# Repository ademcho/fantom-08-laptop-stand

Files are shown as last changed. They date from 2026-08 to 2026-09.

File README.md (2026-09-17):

# Fantom-08 laptop stand

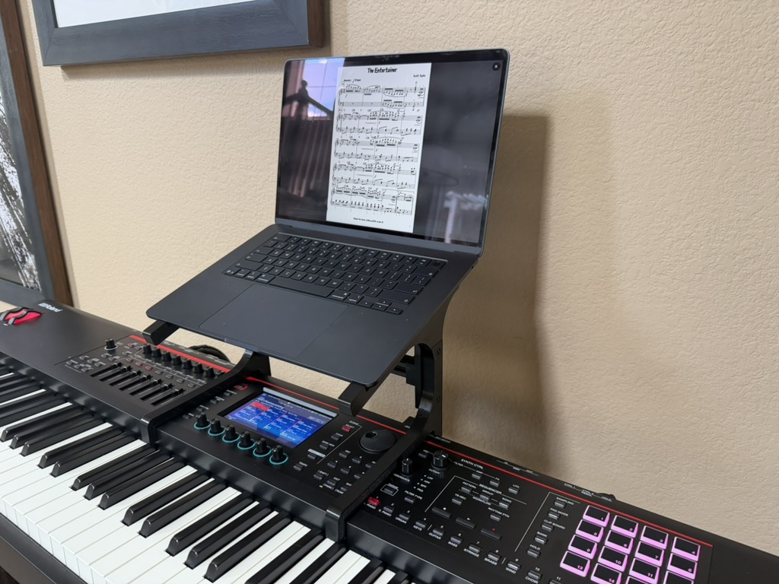
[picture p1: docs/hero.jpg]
Laptop on the stand above a Fantom-08


Clip-on laptop stand for a Roland Fantom-08. Print two brackets; they hook over the rear
panel and under the case bottom at the two clear spots on the panel. Laptop sits on the
15° tray. An optional cross brace (a 2020 aluminum extrusion between the brackets) stiffens
the pair side-to-side.

Design lives in Onshape: `Part Studio 1` is the source profile (one sketch + 15 mm extrude).
`Fantom Stand - Bracket 1.2 split` and `Fantom Stand - Brace mount` are generated.

| | |
|---|---|
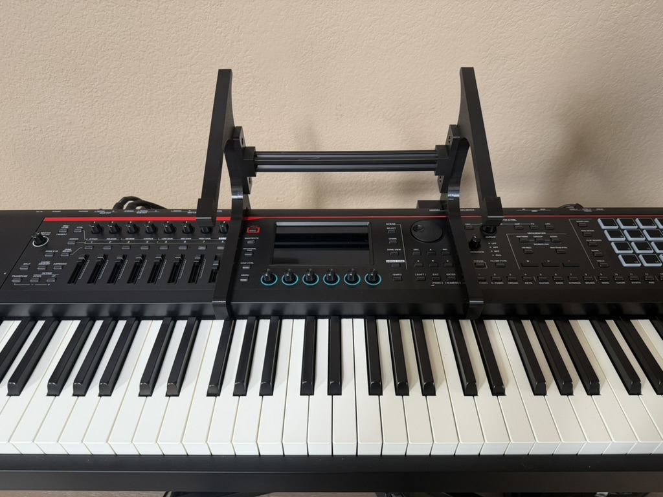
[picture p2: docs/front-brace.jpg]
Both brackets with the 2020 extrusion brace
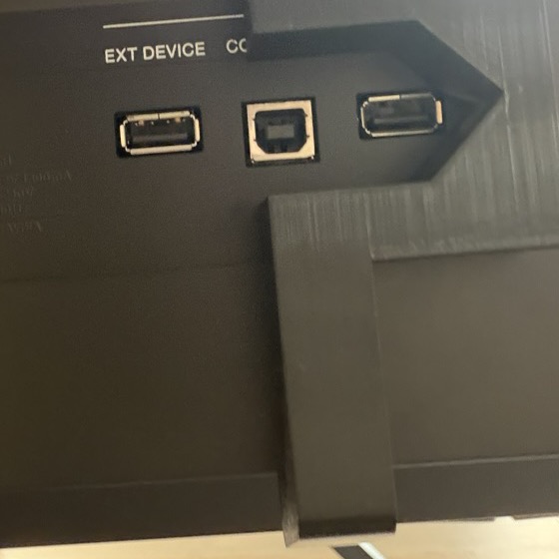
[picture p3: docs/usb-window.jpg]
The USB window clearing the rear ports
|  |  |

## Print

The bracket is 286 mm tall — too big for a 256 mm bed — so it's split on the post with an
86 mm half-lap joint. Print one **A** set and one **B** set (B is mirrored so that, with the
brackets facing each other, both keep their nut pockets on the outer face and a flat inner
face for the brace plate). A halves only mate with A, B with B — the lap is handed.

| file | size (mm) | qty | lay on bed |
|---|---|---|---|
| `exports/bracket_bottom_A.stl` / `_B` | 200 × 221 × 15 | 1 each | nut-pocket face down |
| `exports/bracket_top_A.stl` / `_B` | 213 × 144 × 15 | 1 each | plain face down (tongue step up) |
| `exports/bracket_bottom_B_usb.stl` | 200 × 221 × 46 | instead of `_B` on a Fantom-08 | nut-pocket face down |
| `exports/brace_mount.stl` | 28 × 90 × 20 | 2 | flat back down |

The player's-right bracket lands on the rear USB cluster, so its bottom half is `_B_usb`: the post
is cut away over the port band (28 mm wide, 6 mm vertical margin on your 54 / 28 mm measurements)
and rerouted as a hump on the inner face with a 45° gable roof, so it still prints flat with no
supports. Constants are at the bottom of `tools/split.py` if the ports sit elsewhere.

Flat, no supports. PETG, 4+ walls, 30 %+ infill. Layers run along the post and tray, which
is the strong direction; never print these standing up.

### Replacement bottoms: more key clearance (2026-09-16)

The downward key-facing hook is now **2.5 mm shorter** (17.5 mm below the arm,
previously 20 mm). The 170 mm opening, top halves, lap joints, brace attachment and
USB window remain unchanged. Existing owners only need to reprint the two bottoms.

Open [bottom_brackets_key_clearance_X2D.3mf](exports/bottom_brackets_key_clearance_X2D.3mf)
in Bambu Studio and print **both plates**: plate 1 is right B with USB clearance;
plate 2 is left A. They are already flat, nut-pocket face down. PETG, 0.4 mm nozzle,
0.20 mm layers, 4 walls, 30% infill, **no supports**. Estimated total: **137 g / 3 h 53 min**.
Select your actual bed and PETG, then re-slice; the project contains no cached G-code.
Check clearance with the nearby keys released and pressed after installation.

The source Onshape export is retained; `HOOK_SHORTEN` in `tools/split.py` applies
this trim on regeneration. CAD comparison confirmed only the hook tips changed,
upper STLs are byte-identical, and both bottoms sliced without mesh repairs or
skipped/out-of-bed objects. [Verification record](exports/bottom_reprint_check.json).

### Fully printable brace (alternative to the extrusion)

No aluminum, no extra fasteners: a telescoping square tube that plugs into the same brace
plate sockets and is captive once the brackets are mounted. Measure plate face to plate
face, set `SPAN` in `tools/brace_beam.py`, run it, print what it lists (1, 2, or 3 pieces
depending on span; up to ~625 mm). Tube bores have a 45° roof — insert rods roof-up.
Lighter duty than the extrusion; use the extrusion if the frame ever feels rubbery.

### Fit coupons

`tools/coupons.py` generates thin (5 mm) slices of the clamp profile with the opening
(rear wall → keybed lip) enlarged by +1.0/+1.5/+2.0/+2.5 mm —
`exports/coupon_plus*.stl`, size engraved on each. Print flat, 2 walls / ~10 % infill.
The stretch is mid-arm only; post, foot, and joint are untouched, so the winning delta
can be applied to the arm length in the source sketch without breaking the lap joint.
The +1.0 coupon won (2026-09-06): the sketch now has the opening at 170 mm, and the arm
over the rear panel was dropped from 20 to 12 mm tall at the same time — it only bears on
the panel and pulls on the lip, and the lower bar is ~5× easier to spring on and blocks
less of the panel. Coupons are still cut from the current profile if you need to re-run.

## Hardware

- 4 × M4 pan head, **×20 without brace / ×25–30 with brace** (2 per bracket; they are the
  lap-joint bolts, and with the brace the same bolts also hold the brace plates)
- 4 × M4 hex nut — drops into the hex pocket on the bracket's outer face
- 1 × 2020 aluminum extrusion (European standard, 6 mm slot), cut to plate face to plate
  face + 2 × 10 mm sockets, a couple of mm short: **260 mm** for the measured 11⅛" (282.6 mm)
  bracket spacing (plate faces 242.6 apart)
- optional: 2 × M5 × 16 pan head, self-tapped into the extrusion's ~4.2 mm center bore
  through the back of each brace plate (the extrusion is already captive once both brackets
  are mounted; the screws only matter if you want the frame rigid off the keyboard)

Example Amazon (US) sources, checked 2026-08-30: M4 assortment kit with nuts+washers
[B08FQRWWCM](https://www.amazon.com/dp/B08FQRWWCM) ~$9 · 2020 extrusion 2×1000 mm
[B08934HPRR](https://www.amazon.com/dp/B08934HPRR) ~$30 (or ZYLtech
[B07Z787MB8](https://www.amazon.com/dp/B07Z787MB8)) · M5×16
[B009TE2OMU](https://www.amazon.com/dp/B009TE2OMU). Any European-standard 2020 with a
6 mm slot works; if the M5 spins in the bore, tap it M5 or use thread-locker.

## Assembly

1. Slide each bracket's tongues together (A with A, B with B).
2. Braceless: M4×20 from the plain face, nut in the hex pocket, tighten. Done.
3. With brace: screw the extrusion into the two brace plates first (optional M5s through
   the plate backs), then bolt each plate over a bracket's inner face — M4×25 through
   plate + bracket, head sunk in the plate's counterbore, nut in the bracket's hex pocket.

## Regenerate after editing the profile

```
.venv/bin/python tools/fetch_step.py   # pulls exports/bracket_current.step from Onshape
.venv/bin/python tools/split.py
.venv/bin/python tools/brace.py
```

`tools/onshape.py` is a tiny authenticated GET/POST wrapper (creds in
`~/.config/onshape/credentials.env`). Joint and brace parameters (lap span, bolt positions,
clearances, socket size) sit at the top of `split.py` / `brace.py`; bolt positions must match
between the two.

## License

Models, exports, and code: [CC BY 4.0](LICENSE). Print it, remix it, sell it; just credit
Abe Demcho and link back here.

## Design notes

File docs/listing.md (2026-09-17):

# Listing copy for Printables / MakerWorld / Thingiverse

Paste-ready. Same text on all three; only the upload set differs (below).

## Title

Fantom-08 clip-on laptop stand (no drilling, removable, with cross brace)

## Summary (one line)

Two printed brackets hook the Roland Fantom-08 rear panel and hold a laptop on a 15° tray above the keys. No screws into the keyboard, on and off in seconds.

## Description

I wanted my laptop above my Fantom-08 without a separate stand taking floor space. These two brackets hook over the rear panel and under the case at the two clear spots on the back, and hold a 15° tray about 10 cm above the top panel. Nothing touches the keys or the screen, and it lifts straight off.

**What you get**

- Two brackets, each printed in two halves (they're 280 mm tall, too big for a 256 mm bed) joined by an 86 mm half-lap with two M4 bolts. The joint is stiffer than the print itself.
- The right-hand bracket has a window that clears the rear USB cluster; the post reroutes around it on the inside with a 45° gable so it still prints flat, no supports.
- Optional cross brace between the brackets: either a 2020 aluminum extrusion in printed socket plates, or a fully printed telescoping square tube. Braceless is fine for a 14"; use the brace for a 16" or if you move the keyboard around.
- Fit coupons: 5 mm slices of the clamp profile in +1.0 / +1.5 / +2.0 / +2.5 mm so you can check the opening on your unit before printing 200 g of PETG. My Fantom-08 wanted +1.0, and that's already in the main files.

**Key-clearance revision (2026-09-16):** the downward hook is 2.5 mm shorter.
Existing owners can reuse the upper halves and reprint only bottom A and bottom B USB.
The GitHub repo includes an X2D project containing just these two replacements.

**Print**

PETG, 0.2 mm layers, 4+ walls, 30 %+ infill. Every part lies flat, no supports. Print the halves with the layers running along the post and tray (the strong direction); never stand them up. Right-hand bottom half uses the `_usb` file. Hardware: 4 × M4×20 pan head (×25 with the brace plates), 4 × M4 nuts. Full instructions, cut lengths, and the source in the GitHub repo.

**Source**

Profile is an Onshape sketch; the splitting, joint, brace, and coupons are generated with build123d (Python). Repo: https://github.com/ademcho/fantom-08-laptop-stand · Onshape: https://cad.onshape.com/documents/9a86687b513359acbe40631b

Only tested on the Fantom-08. The 06 and 07 have the same case, so it should fit, but measure your rear panel: the opening is 170 mm rear wall to keybed lip and the panel is 96 mm tall.

## Files to upload

| file | qty | note |
|---|---|---|
| bracket_bottom_A.stl | 1 | left |
| bracket_bottom_B_usb.stl | 1 | right, with USB window |
| bracket_top_A.stl | 1 | |
| bracket_top_B.stl | 1 | |
| brace_mount.stl | 2 | only with the extrusion brace |
| brace_outer.stl, brace_inner.stl | 1 each | only with the printed brace |
| coupon_plus1.0mm.stl … plus2.5mm | optional | fit test |

Skip bracket_bottom_B.stl (plain right side) unless someone asks; it's in the repo.

## Print settings (the form fields)

Printer: any 256 mm bed · Material: PETG · Layer: 0.2 · Walls: 4 · Infill: 30 % gyroid · Supports: none · Rafts: none · Filament: ~280 g total for four halves.

## Tags

roland, fantom, fantom-08, fantom08, keyboard, synthesizer, laptop-stand, laptop, music, studio, stand, bracket, clip-on, petg

## Category

Printables: Hobby & Makers → Music · MakerWorld: Music · Thingiverse: Music

## Photos to take (the listing lives or dies on the first one)

1. Hero: the whole keyboard from the player's side, laptop open on the stand, screen on. Slightly above eye level, landscape.
2. Rear three-quarter: shows both brackets hooking the panel and the brace. This is the one people study.
3. Close-up of the USB window with a cable plugged in.
4. Close-up of the lap joint with the bolts, before the brace plate goes on.
5. All parts laid out on the bed or a table, so people see the print count.
6. Optional: the laptop lid closed, to show it doesn't block the screen or the keys.

Phone is fine. Daylight, no flash, wipe the dust off the Fantom first.

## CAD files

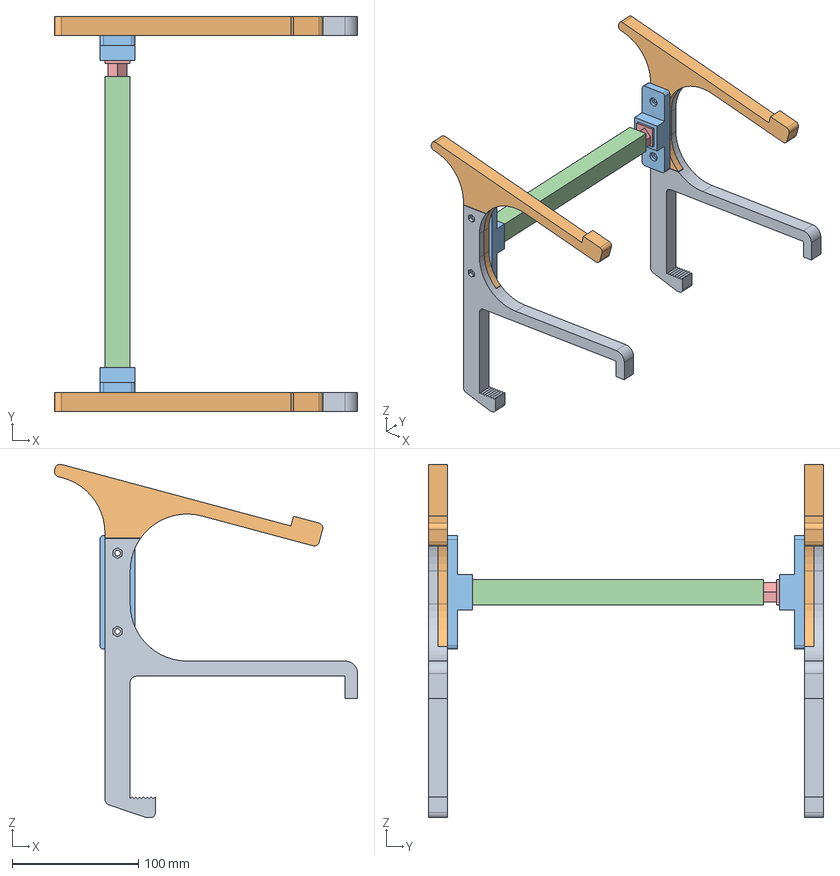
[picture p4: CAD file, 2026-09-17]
exports/full_assembly.step
240.0 x 312.6 x 279.7 mm
Bracket A bottom (clamp)
Bracket A top (tray)
Bracket B bottom (clamp)
Bracket B top (tray)
Brace plate A
Brace plate B
Brace outer tube
Brace inner rod

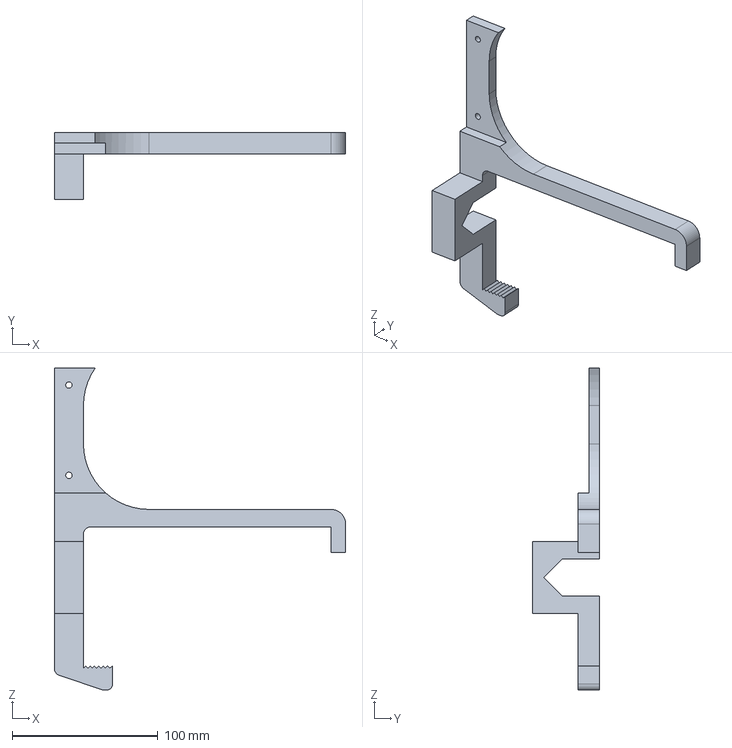
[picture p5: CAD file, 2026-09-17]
exports/bracket_bottom_B_usb.step
200.0 x 46.2 x 221.1 mm

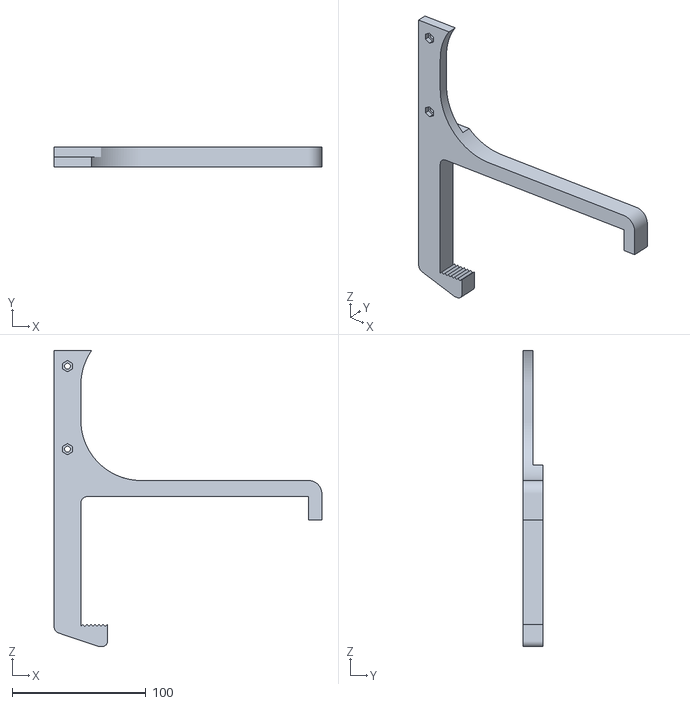
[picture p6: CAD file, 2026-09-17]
exports/bracket_bottom_A.stl
200.0 x 15.0 x 221.1

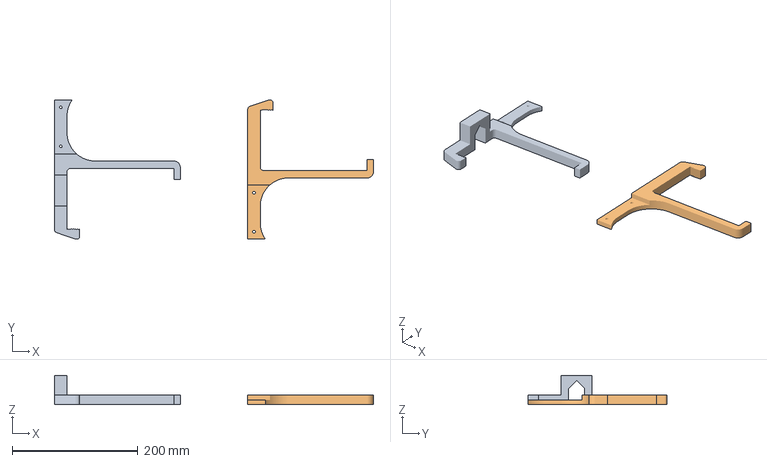
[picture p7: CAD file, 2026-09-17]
exports/bottom_brackets_key_clearance_X2D.3mf
507.2 x 221.1 x 46.2 mm
Right bottom B USB - hook shortened 2.5 mm
Left bottom A - hook shortened 2.5 mm

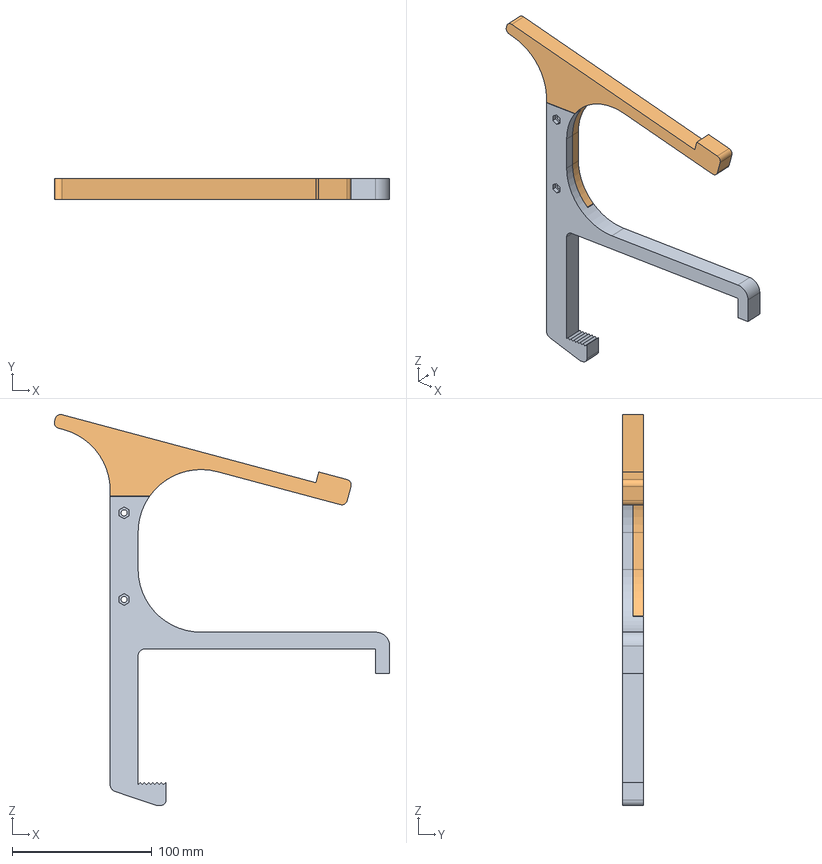
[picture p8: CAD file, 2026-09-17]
exports/bracket_split.step
240.0 x 15.0 x 279.7 mm

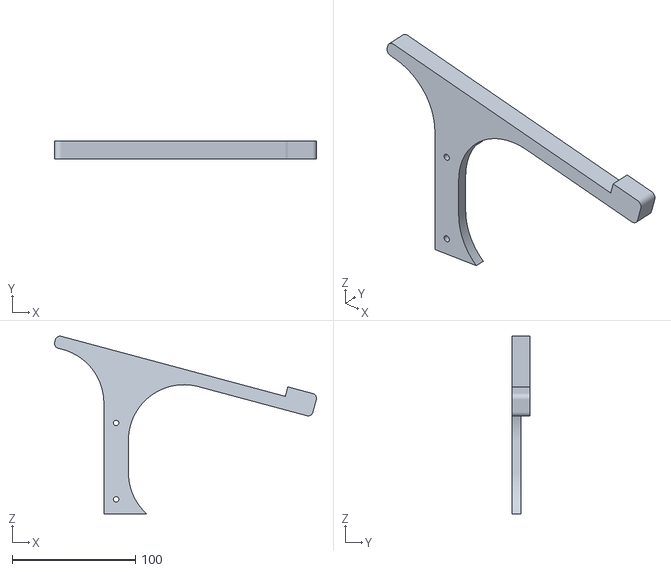
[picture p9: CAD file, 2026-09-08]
exports/bracket_top_B.stl
212.5 x 15.0 x 144.1

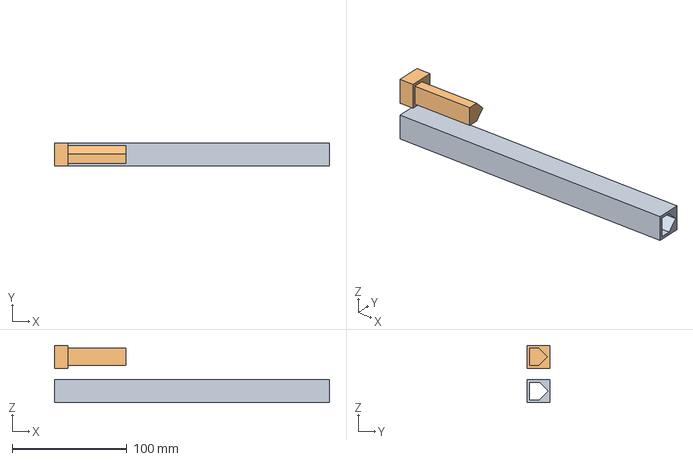
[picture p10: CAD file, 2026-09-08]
exports/brace_beam.step
240.0 x 20.0 x 50.0 mm

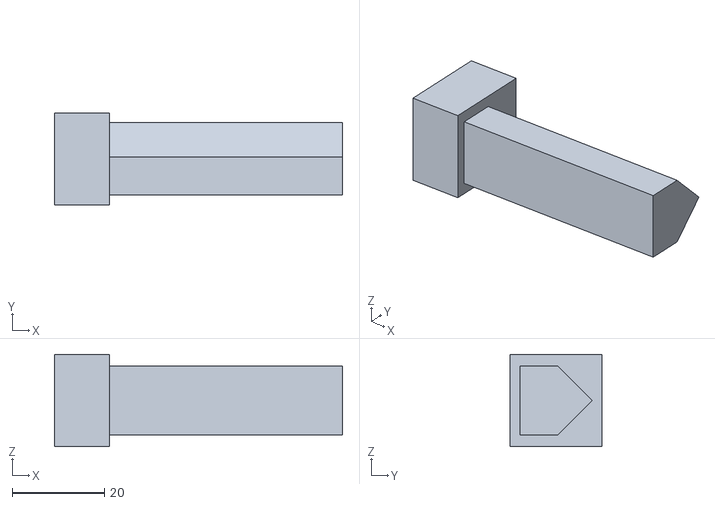
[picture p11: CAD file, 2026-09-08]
exports/brace_inner.stl
62.6 x 20.0 x 20.0

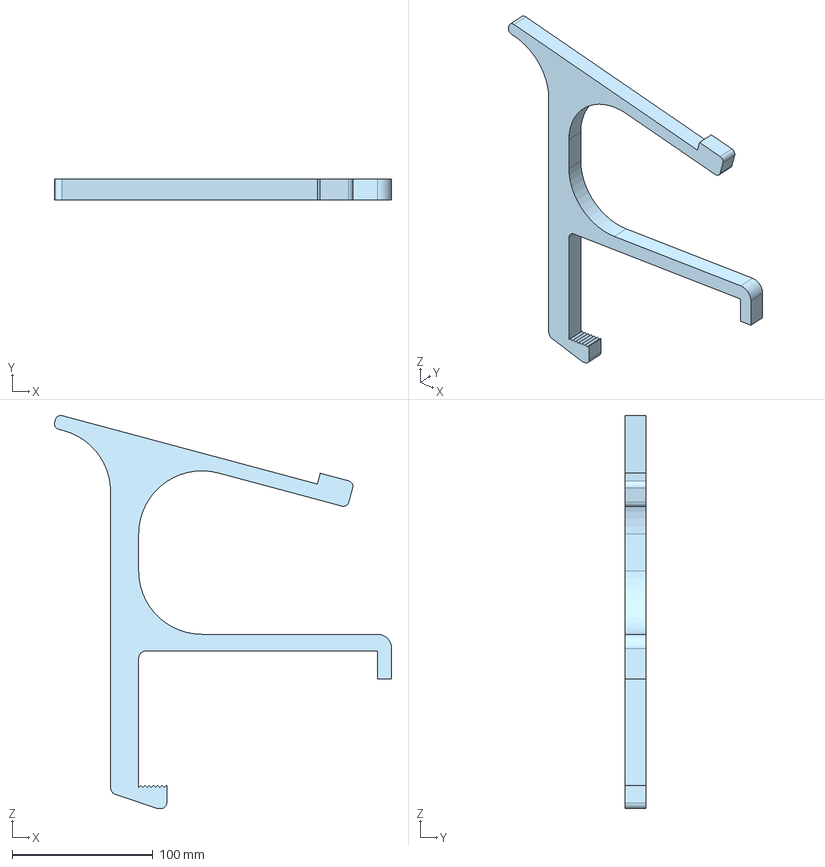
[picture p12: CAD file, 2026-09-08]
exports/bracket_current.step
240.0 x 15.0 x 279.7 mm

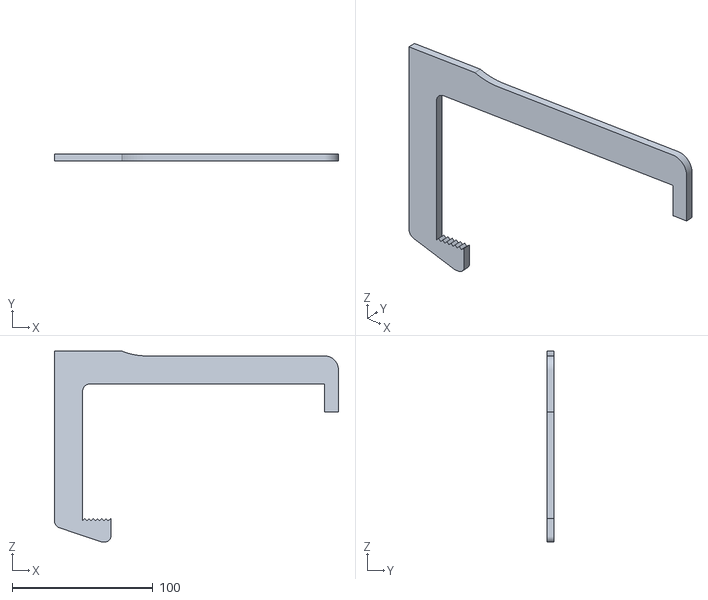
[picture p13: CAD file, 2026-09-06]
exports/coupon_plus2.5mm.stl
201.5 x 5.00 x 135.4

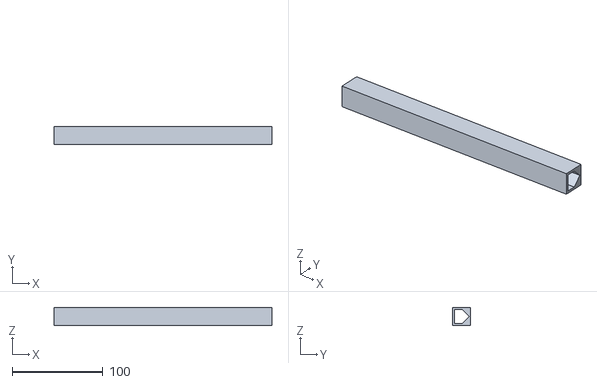
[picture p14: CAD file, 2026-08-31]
exports/brace_outer.stl
240.0 x 20.0 x 20.0

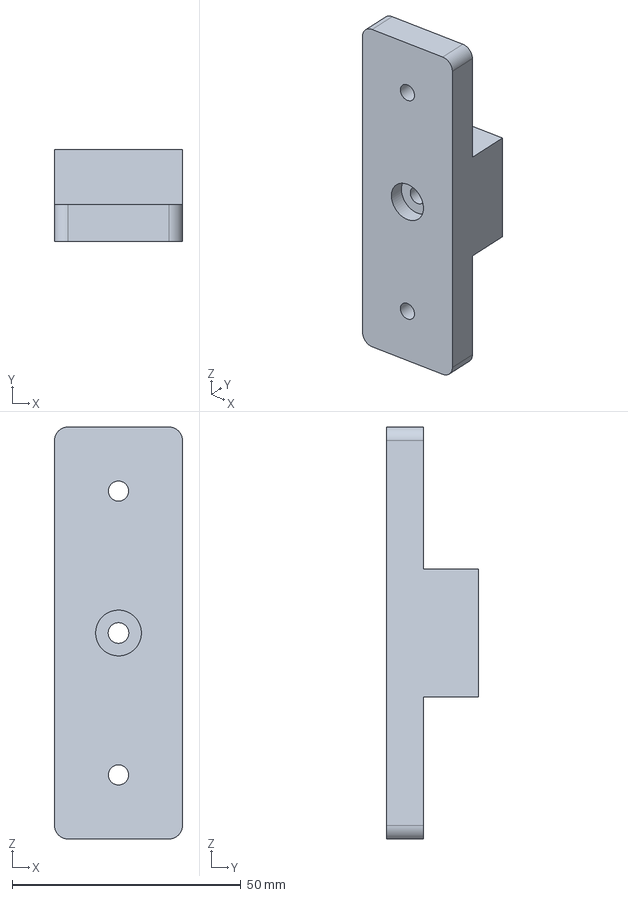
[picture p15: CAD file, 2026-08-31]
exports/brace_mount.step
28.0 x 20.0 x 90.0 mm

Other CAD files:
exports/bracket_bottom_B.stl
exports/bracket_top_A.stl
exports/coupon_plus1.5mm.stl
exports/coupon_plus1.0mm.stl
exports/coupon_plus2.0mm.stl
exports/brace_mount.stl
exports/bracket_bottom_B_usb.stl
exports/bracket_current.stl

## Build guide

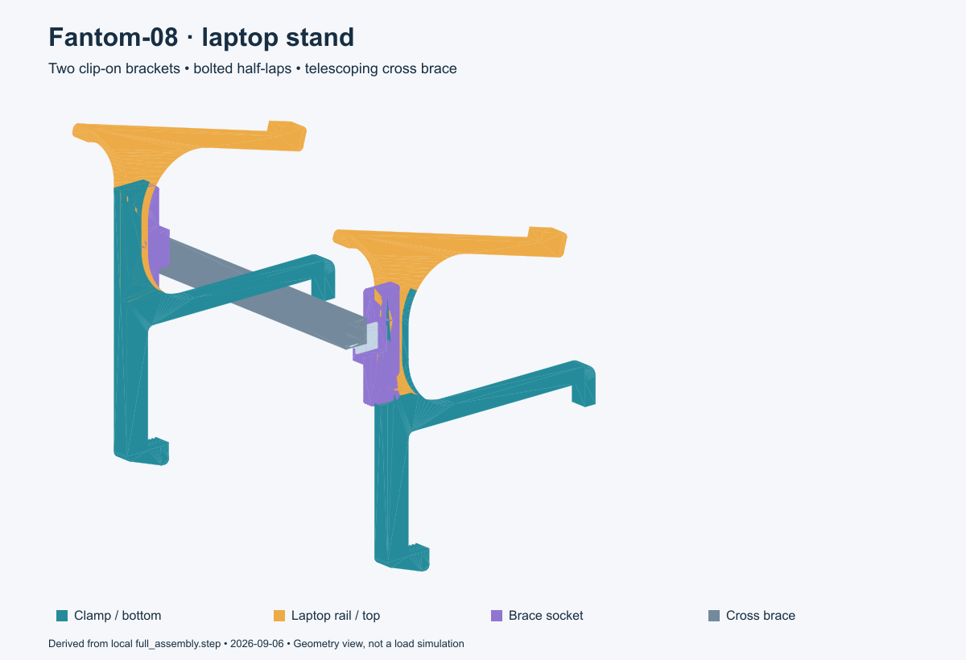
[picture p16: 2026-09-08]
docs/assembly.png

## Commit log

2026-08-31 Split Fantom-08 bracket into two printable halves with bolted half-lap joint
    Bracket is 286mm tall, X2D bed is 256. tools/split.py cuts the Onshape
    part (exports/bracket_current.step) on the post with an 86mm half-lap,
    two M4 through-bolts, hex nut pockets. Both halves print flat.
    Claude-Session: https://claude.ai/code/session_01695Ko4iq4sCYo4ZgQpTrSD
    [bracket_bottom.stl, bracket_current.step, bracket_current.stl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]
2026-08-31 Add 2020-extrusion cross brace mount and mirrored bracket set B
    Brace plate reuses the two joint bolts (no new fasteners), sockets a
    2020 extrusion between the brackets, and stiffens the lap. Set B is
    mirrored so nut pockets face outward on both brackets and the plates
    sit on flat inner faces. README: hardware list with Amazon sources.
    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
    [brace_mount.step, brace_mount.stl, bracket_bottom_A.stl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]
2026-08-31 Add fully printable telescoping cross brace
    Square tube + rod that plug into the same brace plate sockets as the
    2020 extrusion. Telescope absorbs span uncertainty; no fasteners, the
    beam is captive once brackets are clamped. 1/2/3 pieces by SPAN, 45-deg
    bore roof so it prints flat without supports.
    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
    [brace_beam.step, brace_inner.stl, brace_outer.stl]
2026-09-02 Add assembled scene of all parts (brackets, plates, telescoping brace)
    tools/assembly_view.py places every part with exact math, asserts no
    collisions, exports exports/full_assembly.step. Span placeholder 400mm.
    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
    [full_assembly.step]
2026-09-02 Bake world transforms into geometry before STEP export
    Onshape's importer drops lazy child placements from build123d compounds,
    so all assembly parts landed at origin. Boolean with a big box forces
    the coordinates into the geometry.
    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
    [full_assembly.step]
2026-09-02 Fix dropped assembly part: import brace plate twice
    build123d's STEP writer aliases products sharing an underlying shape
    and silently drops one; a second import_step gives plate A its own
    shape. Round-trip self-check added (8/8).
    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
    [full_assembly.step]
2026-09-02 Bake part placements with relocate() before STEP export
    Booleans keep a lazy placement plus local geometry; importers apply the
    placement on top of already-offset geometry (parts landed at double
    offset or origin). relocate(Location()) re-expresses geometry globally
    and zeroes the placement; asserts verify bbox and location.
    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
    [full_assembly.step]
2026-09-06 Add clamp-opening fit coupons (+1.0 to +2.5 mm)
    Thin slices of the bottom bracket clamp with the keybed lip shifted
    outboard; labels engraved. First print showed the 169mm opening is
    1-2mm too tight.
    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
    [coupon_plus1.0mm.stl, coupon_plus1.5mm.stl, coupon_plus2.0mm.stl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]
2026-09-08 Apply +1 mm coupon, 12 mm arm, USB bypass, measured spacing; prep for publishing
    - Onshape sketch: opening 169 -> 170 (the +1.0 fit coupon won), arm over the
    rear panel 20 -> 12 mm (tension-only member, easier to spring on)
    - bracket_bottom_B_usb: post cut away over the rear USB cluster and rerouted
    as a gable-roofed hump on the inner face, prints flat without supports
    - SPAN = 242.6 from the measured 11 1/8" bracket spacing; extrusion cut 260
    - tools/fetch_step.py pulls the STEP through the translation API
    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
    [brace_beam.step, brace_inner.stl, bracket_bottom_A.stl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]
2026-09-17 Shorten keybed hooks 2.5 mm and add bottom-only Bambu project
    [bottom_brackets_key_clearance_X2D.3mf, bracket_bottom_A.stl, bracket_bottom_B.stl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]
2026-10-18 Add cup and cable holder revisions, print projects and verification notes
